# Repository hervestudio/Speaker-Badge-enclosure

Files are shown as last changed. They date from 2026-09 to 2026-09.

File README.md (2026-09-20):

# Speaker Badge — enclosure (print-ready STL)

3D-printable enclosure for the **threejs.paris speaker badge**: an ESP32-S3
conference badge with a 2.1" round 360×360 TFT, three buttons, a LiPo battery
and a lanyard bar.

This repo holds only the **print-ready STL files for the Medium body**
(66 × 134 mm, the size the 40-badge run was built with). The parametric
build123d source that generates them lives in
[hervestudio/speaker-badges](https://github.com/hervestudio/speaker-badges),
and the firmware in
[hervestudio/firmware-badge](https://github.com/hervestudio/firmware-badge).

| | |
|---|---|
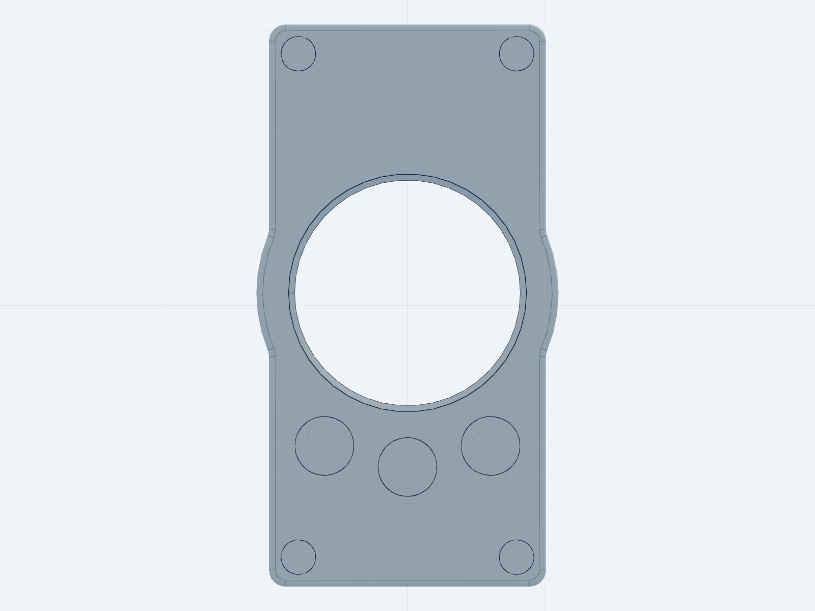
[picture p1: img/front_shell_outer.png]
Front shell, outer face
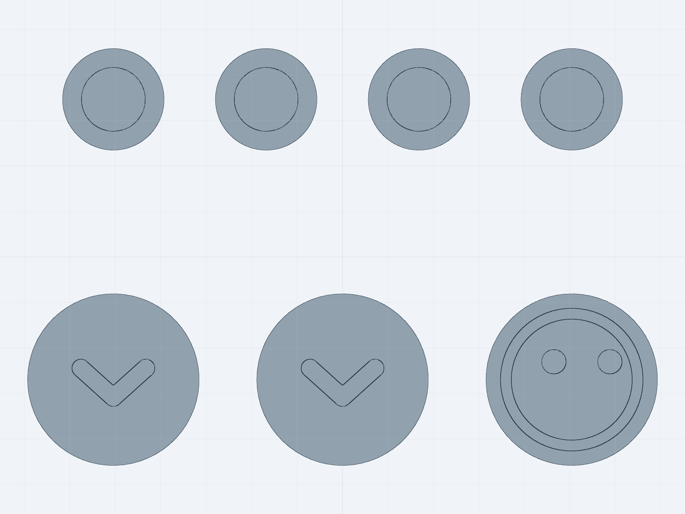
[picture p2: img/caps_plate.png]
Button caps and screw caps on one plate
|  |  |
| `front_shell_medium.stl` — screen cutout, three button counterbores, four screw counterbores. The counterbores look filled because each is closed by a sacrificial membrane (see [After printing](#after-printing)). | `small_parts_plate.stl` — the three button caps and the four screw caps laid out for a single print. |

## Choose your back shell

| | |
|---|---|
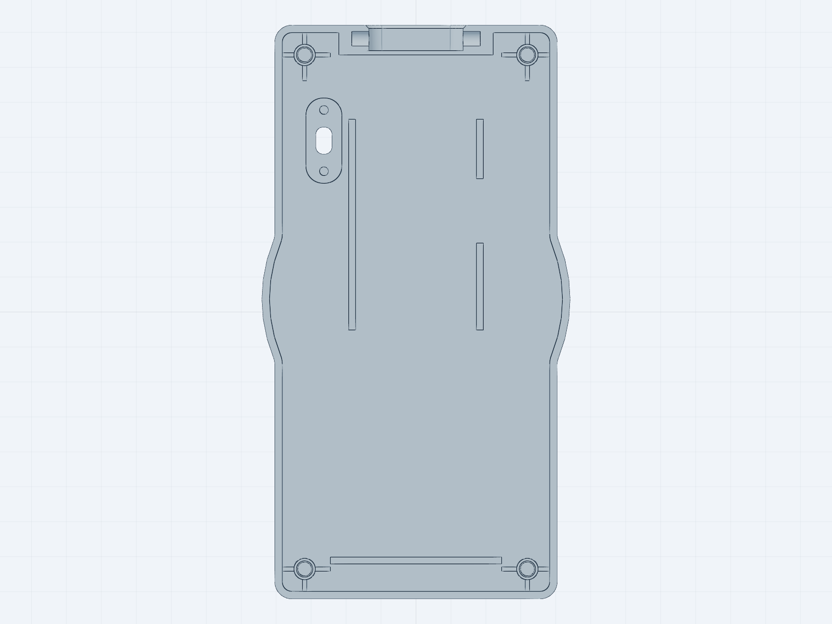
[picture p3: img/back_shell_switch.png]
Back shell with the power-switch housing
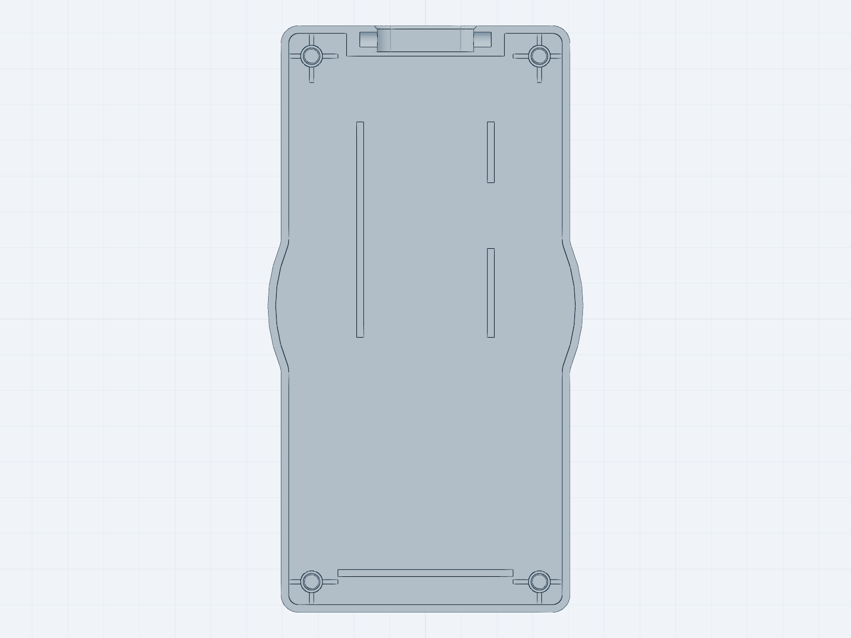
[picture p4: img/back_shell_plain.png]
Back shell without it
|  |  |
| `back_shell_medium_switch.stl` | `back_shell_medium.stl` |

Print **one** of the two. They are identical except for the switch housing,
visible top-left above: the flange recess, the lever slot and the two
retaining pins.

**`back_shell_medium_switch.stl` — recommended.** Adds a housing for a
physical power switch: a recess for the switch flange, a through slot for the
lever, a shallow finger dish around it on the outside, and two Ø2.0 mm pins
you melt over the flange holes with a soldering iron to retain it. Sized for a
**TRU TC-R13-603C-05 / SCI R13-603** slide switch (SPDT, 3 A, 19.5 × 8 mm
flange, 14.3 mm hole pitch, 5.8 mm body depth).

**`back_shell_medium.stl` — original.** The back as it was printed for the
event, no switch.

> **Why you want the switch.** The original badge had no way to physically cut
> the battery. The 5 V boost converter keeps drawing ~0.3 mA even with the
> firmware "off", which after the event drained the cells below their
> protection cutoff — most of them never recovered. Wire the switch in series
> on the battery **+** line, between the cell and the TP4056 `B+` pad: in the
> OFF position nothing draws current at all. Note that the badge then only
> charges with the switch ON.

## What to print

| File | Qty per badge | Notes |
|---|---|---|
| `front_shell_medium.stl` | 1 | Screen side |
| `back_shell_medium_switch.stl` **or** `back_shell_medium.stl` | 1 | See above |
| `button_cap_side.stl` | 2 | Chevron icon, both sides identical |
| `button_cap_center.stl` | 1 | Smiley icon |
| `screw_cap.stl` | 4 | Decorative caps over the screw heads |
| `small_parts_plate.stl` | — | All 7 caps above on a single plate, for one print |

## Print settings

Tested on a **Bambu Lab A1 in PLA**, 0.2 mm layers, 2 walls, 15 % infill,
**no supports and no brim**.

- **Shells**: print in their native orientation — **outer face down, cavity
  opening up**. In that pose the USB cutout, the lanyard slot and the button
  holes are all open notches at the top, so nothing needs support.
- **Caps**: they are already lying flat, **engraved face against the plate**.
  Printing them face-down is what makes the icons come out crisp.
- Useful tweaks from the production run: `elephant foot compensation 0`,
  `initial layer line width 0.45`, bottom surface pattern `monotonic line`.

**Two-colour caps** (coloured icon on a black cap) need no separate model: the
icon is engraved 0.4 mm deep, which is exactly 2 layers at 0.2 mm. Slice a cap
normally and insert a filament change at the start of layer 3 — colour for
layers 1-2, black from layer 3 up.

## After printing

- **Pierce the sacrificial membranes.** The screw-cap counterbores and the
  button counterbores are closed by a single 0.2 mm layer, so the ceiling above
  them prints over solid material instead of bridging over a hole. Push them
  out with the tip of an M2 screw or a craft knife before assembly.
- **Heat-set the 4 brass inserts** (M2, H4, Ø3.2) into the back shell's blind
  holes, pressed in from the seam side.
- **Closing screws**: 4 × **M2 × 12 mm** countersunk. 12 mm, not 10 — the front
  face is 8.75 mm thick, and an M2 × 10 barely bites into the insert.

The full pin-by-pin wiring and assembly guide is
[`tools/montage-badge.html`](https://github.com/hervestudio/firmware-badge/blob/main/tools/montage-badge.html)
in the firmware repo (open it in a browser).

## Electronics

Not in this repo. The bill of materials, the wiring and the firmware are in
[hervestudio/firmware-badge](https://github.com/hervestudio/firmware-badge) —
and you can try the badge in your browser, without any hardware, at
**https://hervestudio.github.io/firmware-badge/**.

## License

MIT — see [LICENSE](LICENSE).

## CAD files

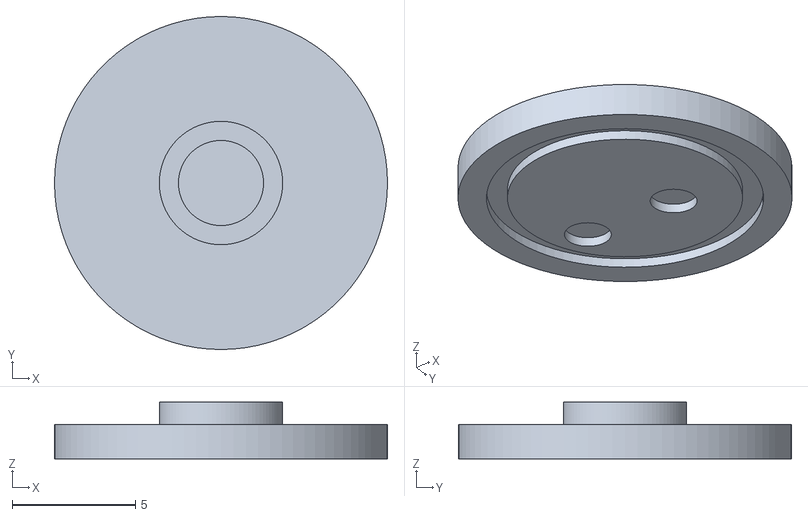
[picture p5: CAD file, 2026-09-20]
button_cap_center.stl
13.5 x 13.5 x 2.30

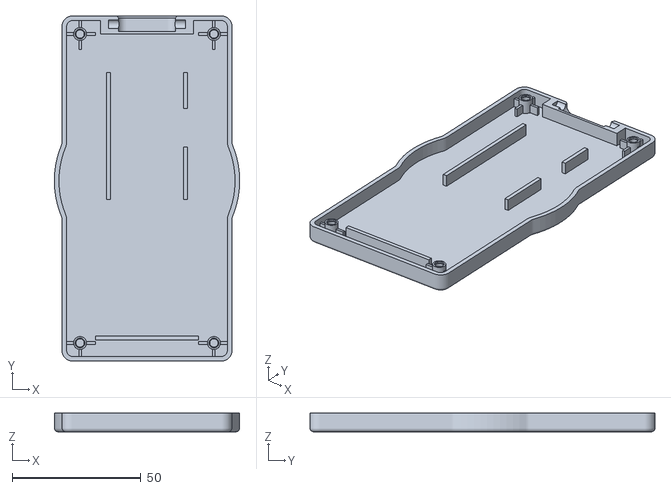
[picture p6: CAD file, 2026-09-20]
back_shell_medium.stl
72.0 x 134.0 x 7.25

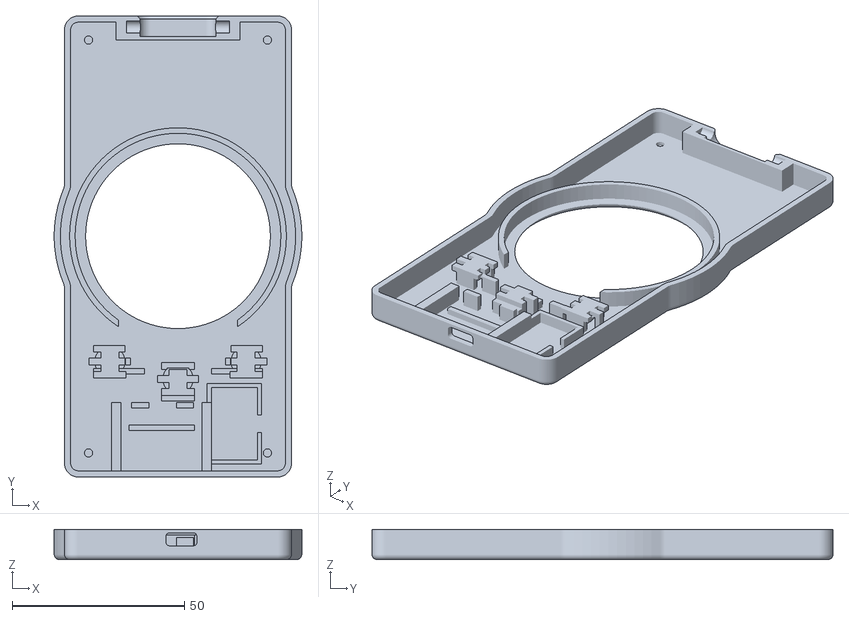
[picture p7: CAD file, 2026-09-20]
front_shell_medium.stl
72.0 x 134.0 x 8.75

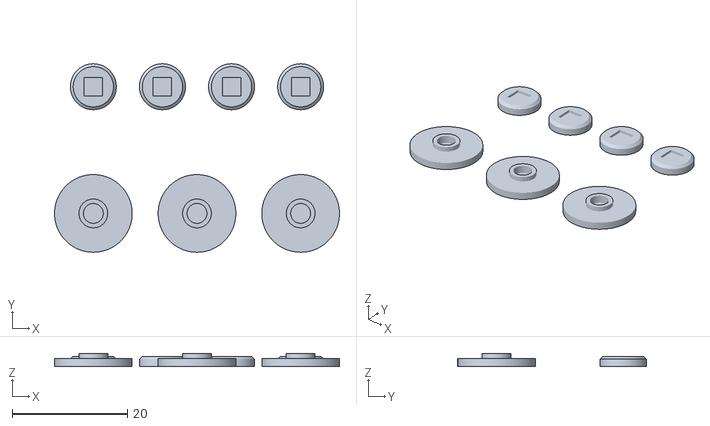
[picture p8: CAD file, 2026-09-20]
small_parts_plate.stl
49.5 x 32.8 x 2.30

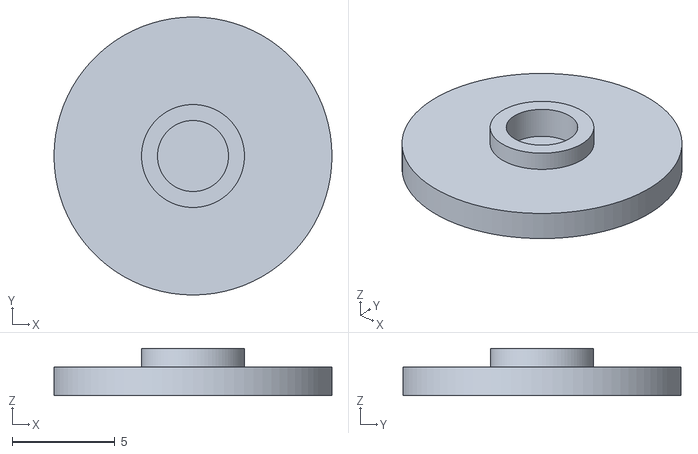
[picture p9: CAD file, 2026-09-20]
button_cap_side.stl
13.5 x 13.5 x 2.30

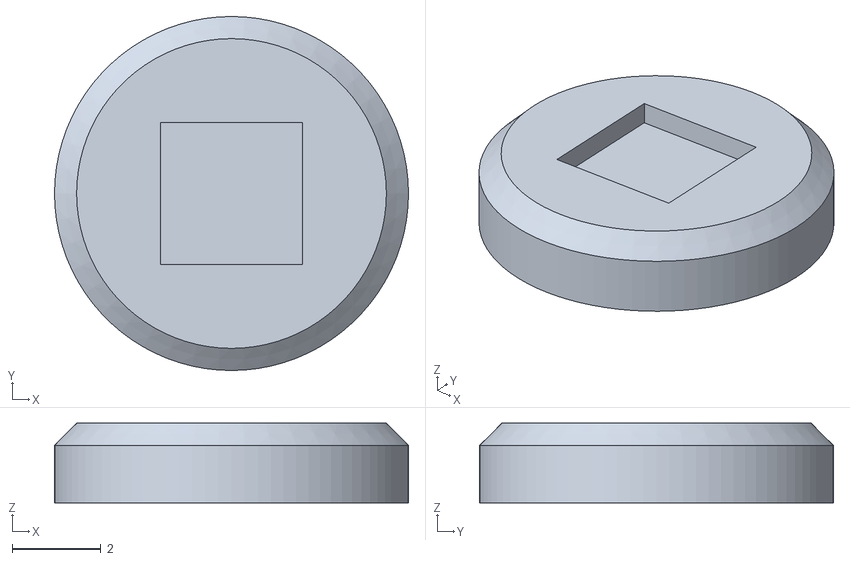
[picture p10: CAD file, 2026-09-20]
screw_cap.stl
8.00 x 8.00 x 1.80

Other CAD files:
back_shell_medium_switch.stl

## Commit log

2026-09-20 Print-ready enclosure STLs for the Medium speaker badge
    Front shell, both back-shell variants (with and without the physical
    power-switch housing), button caps, screw caps and a combined small-parts
    plate. All meshes verified watertight; generated from the build123d source
    in hervestudio/speaker-badges.
    [back_shell_medium.stl, back_shell_medium_switch.stl, button_cap_center.stl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]
2026-09-20 README: add front shell and small-parts plate renders
2026-09-20 README: fix the front shell and caps renders, which were upside down
    Both were shot from an azimuth that rotated the view 180 degrees: the
    buttons appeared above the screen instead of below it, and the side-cap
    chevrons read as 'up' while the part engraves a 'down' chevron (the
    smiley's mouth arc also read as a plain ring).
